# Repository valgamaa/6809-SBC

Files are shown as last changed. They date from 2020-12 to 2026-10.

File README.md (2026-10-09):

# 6809 SBC

A self-built 6809 single-board computer that runs **FLEX 9** from a
CompactFlash card: schematics and boards, the firmware and drivers that run
on it, and the host-side tools used with it.

## Contents

| Folder | Contents |
|---|---|
| [`hardware/`](hardware/) | Schematics and board files (current version: V6) |
| [`software/`](software/) | Monitor, FLEX BIOS and disk drivers, RTC support, CF tools and the ROM image — see [software/README.md](software/README.md) |
| [`tools/octave/`](tools/octave/) | Octave scripts for FLEX disk images and S-record handling |

The companion Mac application [A09Studio](https://github.com/valgamaa/A09Studio)
assembles the code, programs the ROM, sends FLEX disk images to the CF card,
and browses and builds FLEX disks.

## Licence

The code in this repository is released under the [MIT licence](LICENSE).
Parts derive from third-party software; see [NOTICE.md](NOTICE.md). FLEX and
TSC programs are not included and belong to their owners.

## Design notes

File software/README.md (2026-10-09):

# 6809 SBC software

Firmware, drivers and test programs for a self-built 6809 single-board
computer that runs **FLEX 9** from a CompactFlash card.

The board: 6809 CPU, 1 MHz bus from a 4 MHz crystal, MC68681 DUART for the
console, CompactFlash in 16-bit True IDE mode (low byte only), Epson
RTC-72421/72423 real-time clock, and an MC6859 data-security device. The
monitor is a modified **Assist09**; at reset it copies itself from ROM to RAM.

The host-side tools for building these programs and for making and sending
FLEX disk images are in the companion project,
[A09Studio](https://github.com/valgamaa/A09Studio).

## What is here

| Folder | Contents |
|---|---|
| `monitor/` | `Assist09-Flex.asm` — the modified Assist09 monitor: boots FLEX, reads the RTC and sets FLEX's date, and adds the `F`, `X`, `U` and `K` commands |
| `rtc/` | RTC support: `Assist09_Flex_RTC.asm` (date sync and 1-minute interrupt, called from the monitor), `Flex_DatePatch.asm` (stops FLEX asking for the date), `RTC_Set.asm` (the clock-setting program run by `K`), and RTC test programs |
| `flex-bios/` | `Flex_BIOS.asm` — FLEX's disk and console drivers for the CF card and serial port; `Flex_BIOS_DiskLoader.asm` — receives a FLEX disk image over serial and writes it to the card; `inch_outch_test.asm` — console I/O test |
| `cf-tools/` | `FlexFormat.asm` — formats a FLEX disk on the CF card; `CF_Test_4.asm` — CF card exerciser |
| `rom-images/` | The programmed ROM image (v6) as `.bin` and `.hex` |
| `docs/` | `monitor-commands.md` / [PDF](docs/monitor-commands.pdf) (the added commands), `xbasic-patching.md`, and a spreadsheet of the added commands |

Each source file has a header comment saying what it does and where it lives
in memory. The `.hex` / `.s19` files are assembler output kept for convenience.

## Hardware addresses

| Address | Device |
|---|---|
| `$F000`–`$F7FF` | I/O space (decoded as a 2K block) |
| `$F230` | Epson RTC |
| `$F278` | MC6859 (responds in the top 8 bytes of its decode window) |
| `$F2C0`, `$F300` | CompactFlash register blocks |
| `$F340` | MC68681 DUART, port A (console) |

Software entry points and load addresses (for example `Flex_BIOS` at `$F800`
with its disk vector table at `$DE00`, the RTC sync routine at `$FB00`, and the
disk loader at `$EE00`) are given in each source file's header comment.

## Building

The sources assemble with the `a09` assembler. For example:

```
a09 -xFlex_BIOS.hex -lFlex_BIOS.lst Flex_BIOS.asm
```

`-x` writes Intel hex, `-s` S-records, `-b` raw binary and `-l` a listing.
A09Studio wraps the same assembler with an editor and a terminal, and drives
a TL866 programmer to burn the ROM.

> TODO: add step-by-step instructions for assembling the pieces into the
> combined ROM image and burning it.

## Bring-up order

1. Burn the ROM image (`rom-images/`) and check the monitor prompt on the serial console.
2. Format the CF card with the monitor's `X` command, or send a whole disk image to it with `U` and the Disk Image tool in A09Studio.
3. Use `K` to set the clock, then boot FLEX with `F`. The monitor sets FLEX's date from the RTC.

The monitor's added commands (`F`, `X`, `U`, `K`) are described in
[docs/monitor-commands.md](docs/monitor-commands.md).

## Using TSC Extended BASIC

TSC XBASIC needs a few per-system patches before it runs on this board. See
[docs/xbasic-patching.md](docs/xbasic-patching.md). The program itself is not
included here.

## Licence

The code in this repository is released under the [MIT licence](../LICENSE).
Parts of it derive from third-party software; see [NOTICE.md](../NOTICE.md).
FLEX and TSC programs are not included and belong to their owners.

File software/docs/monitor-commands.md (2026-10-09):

# Added monitor commands

The monitor is Assist09 with four commands added. All of them use letters
that stock Assist09 does not use (it already uses B, C, D, E, G, L, M, N, O,
P, R, S, T, V and W). The ROM image is
`rom-images/Monolithic-Flex-Assist09-BIOS-Format-Loader_v6`.

| Command | Name | Runs at | Source |
|---|---|---|---|
| `F` | Boot FLEX | `$CD00` | `monitor/Assist09-Flex.asm`, `rtc/Assist09_Flex_RTC.asm`, `rtc/Flex_DatePatch.asm` |
| `X` | Format | `$E900` | `cf-tools/FlexFormat.asm` |
| `U` | Upload | `$EE00` | `flex-bios/Flex_BIOS_DiskLoader.asm` |
| `K` | Clock | `$C000` | `rtc/RTC_Set.asm` |

## `F` — boot FLEX

Starts FLEX, with the date taken from the real-time clock.

1. Reads the RTC and prints it as `DD/MM/YY HH:MM:SS`. If the clock is unset
   or holds an impossible date, it prints a message instead.
2. Writes the date into FLEX's date bytes (`$CC0E`–`$CC10`).
3. Arms the RTC's 1-minute interrupt, so the date stays current without
   anyone typing `DATE`.
4. Waits for the console to finish printing, then starts FLEX.

FLEX skips its "date?" prompt when the date has been set. If the clock can't
be read, FLEX starts with whatever date it already had and the interrupt
stays off. Use `K` to set the clock.

## `X` — format

Starts the disk formatter, which formats the CF card for FLEX. It writes a
new, empty FLEX disk: the System Information Record, an empty directory, and
a free-space chain over the rest of the card. **This erases the disk.**

## `U` — upload

Starts the disk loader. Once it is running, send a disk image from the host
over the serial link and it is written to the CF card, sector by sector. In
A09Studio use the **Disk Image…** tool (or **Send to CF…** from the Disk
Builder or DSK Browser). This overwrites the target drive.

## `K` — clock

Starts the clock program, for setting the time and date from scratch or for
checking a new board. **Starting it stops and resets the clock.** At its
prompt:

| Key | Action |
|---|---|
| `S` | Set the time |
| `E` | Set the date (`DD MM YY`) |
| `I` | Toggle the 1-minute interrupt |
| `Q` | Quit back to the monitor |

After setting the clock, use `F` to boot FLEX with the new date.

## Notes

- The formatter, loader and clock program sit in ROM above or away from user
  RAM, so `$0000`–`$BFFF` stays free. The clock program at `$C000` is
  restored from the ROM image on every reset.
- The monitor masks the RTC interrupt at reset, so a cold power-up can't fire
  it before `F` has installed the handler.

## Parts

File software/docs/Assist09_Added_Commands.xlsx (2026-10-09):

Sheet: Added commands
Command | Name | Address | What it does | Source file
F | Boot Flex | $CD00 | Reads the RTC and prints DD/MM/YY HH:MM:SS (or a message if the clock is unset or invalid). Writes the date to Flex's date bytes at $CC0E-$CC10, arms the 1-minute RTC interrupt, waits for the console to finish printing, then starts Flex. Flex skips its date prompt when the date was set. | Assist09-Flex.asm, Assist09_Flex_RTC.asm, Flex_DatePatch.asm
X | Format | $E900 | Launches the disk formatter to format the CF card for Flex. | FlexFormat.asm
U | Upload | $EE00 | Launches the disk loader. Once running, send a disk image from the host over serial and it writes it to the CF card. | Flex_BIOS_DiskLoader.asm
K | Clock | $C000 | Launches the clock program for setting the time and date from scratch or checking a new board. S sets the time, E sets the date (DD MM YY), I toggles the minute interrupt, Q returns to the monitor. Starting it stops and resets the clock. | RTC_Set.asm

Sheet: Notes
The formatter, loader and clock program sit in ROM above or away from user RAM, so $0000-$BFFF stays free. The clock program at $C000 is restored from the ROM image on every reset.
The monitor masks the RTC interrupt at reset so a cold power-up cannot fire it before F has installed the handler.
Letters already used by stock Assist09: B, C, D, E (encode), G, L, M, N, O, P, R, S, T, V, W.
Image: Monolithic-Flex-Assist09-BIOS-Format-Loader_v6.

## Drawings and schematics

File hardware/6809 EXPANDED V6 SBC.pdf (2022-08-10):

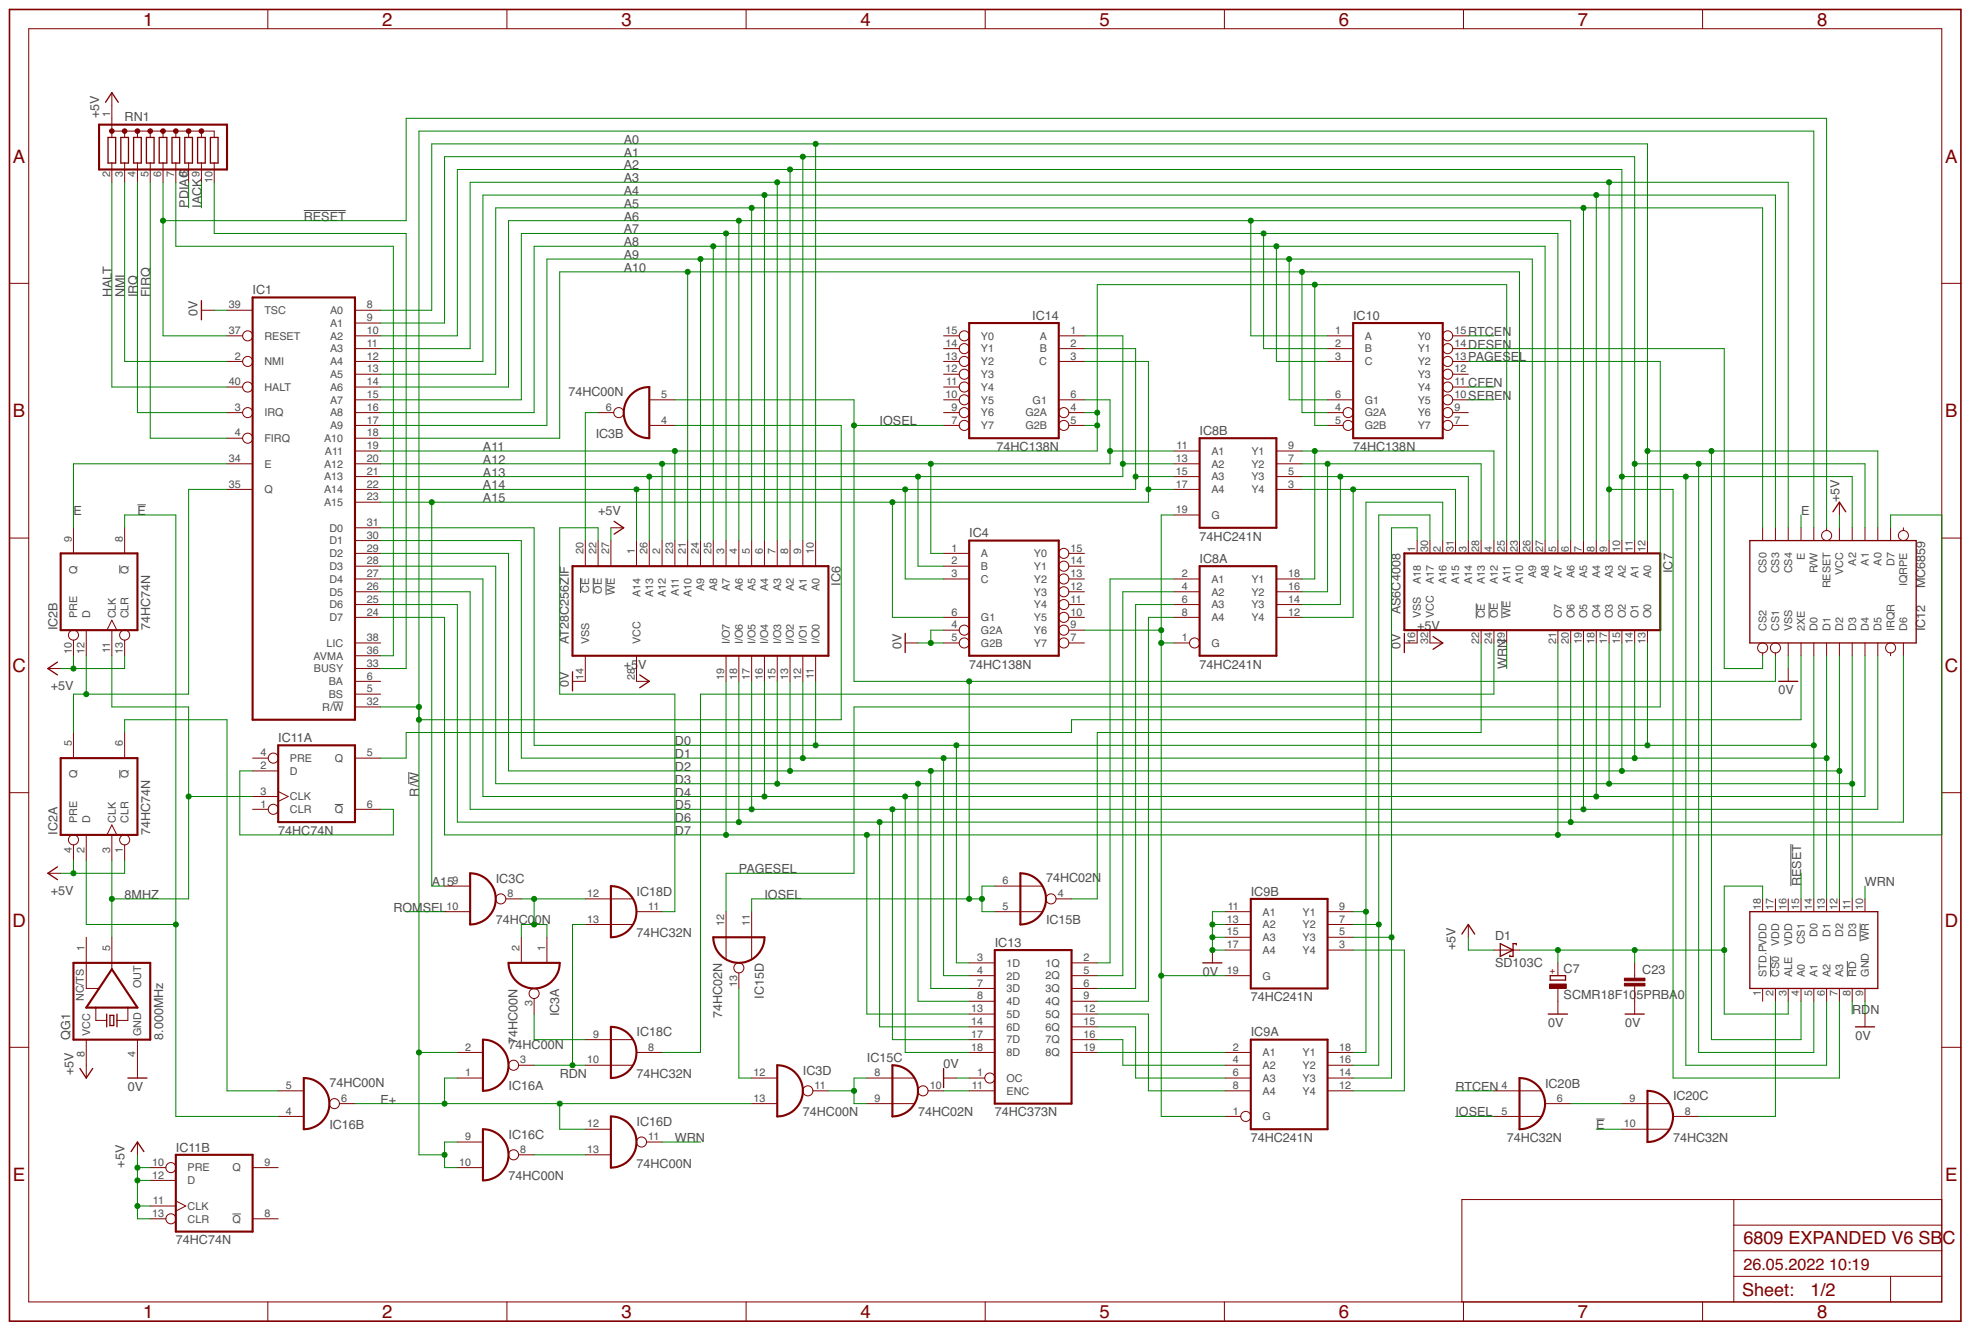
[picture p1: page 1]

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
22 | | A14 | | | | | 3 Y3
23 | | A15 | | | | 19

13 | 7 Y1
15 | 5 Y2

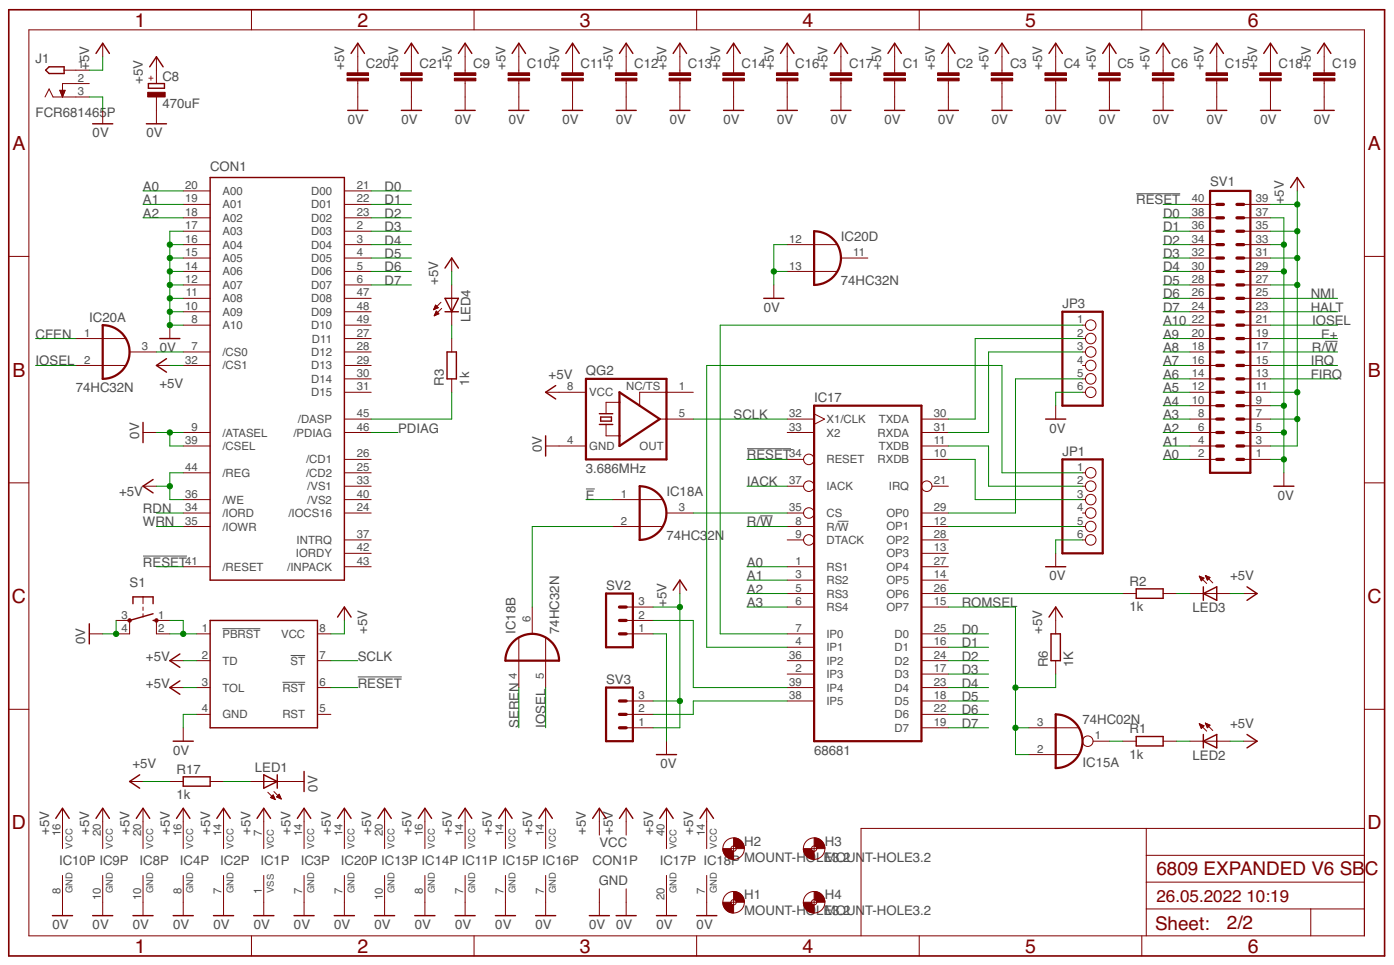
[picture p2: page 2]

CON1

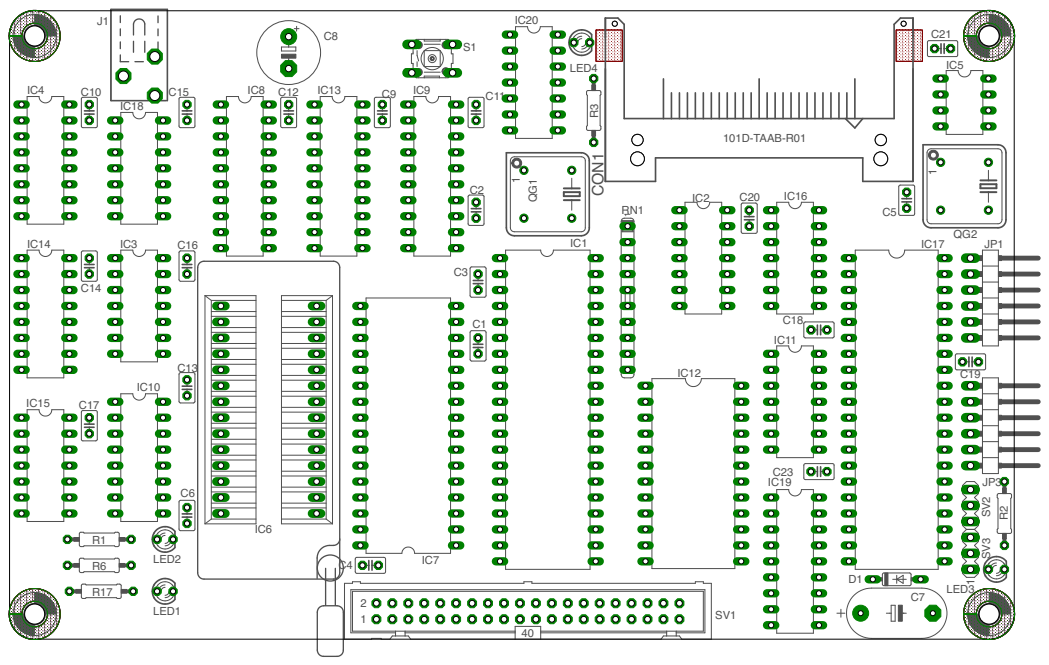
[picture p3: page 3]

Qty Device | PCB Ref. | TME Order Code
1 | B3F-10XX | S1 | SKHHALA010
1 | MI20-50PD-SF | CON1 | 101D-TAAB-R01
2 | MA03-1 | SV2, SV3 | 77311-818-03LF
1 | ML40 | SV1 | ZL231-40PG
2 | 1X06/90 | JP1, JP3 | ZL263-6SG
1 | FCR681465P | J1 | FCR681465P
5 | 1k | R1, R2, R3, R6, R17 | MBB0207C1001FCT00
1 | 4k7 | RN1 | 4610X-101-472LF
20 100n | C1, C2, C3, C4, C5, C6, C9, C10,
| | C11, C12, C13, C14, C15, C16, C17,
| | C18, C19, C20, C21, C23
1 | 470uF | C8 | UVY1E471MPD
1 | SCMR18F105PRBA0 | C7
1 | 3.686MHz | QG2
1 | 8.000MHz | QG1
2 | 74HC00N | IC3, IC16
1 | 74HC02N | IC15
3 | 74HC138N | IC4, IC10, IC14
2 | 74HC241N | IC8, IC9
2 | 74HC32N | IC18, IC20
1 | 74HC373N | IC13
2 | 74HC74N | IC2, IC11
1 | 6809E | IC1
1 | MC68681P | IC17
1 | AS6C4008 | IC7
1 | AT28C256ZIF | IC6
1 | TC1232 | IC5
1 | MC6859 | IC12
1 | RTC72421 | IC19
1 | SD103C | D1
4 | LED3MM | LED1, LED2, LED3, LED4

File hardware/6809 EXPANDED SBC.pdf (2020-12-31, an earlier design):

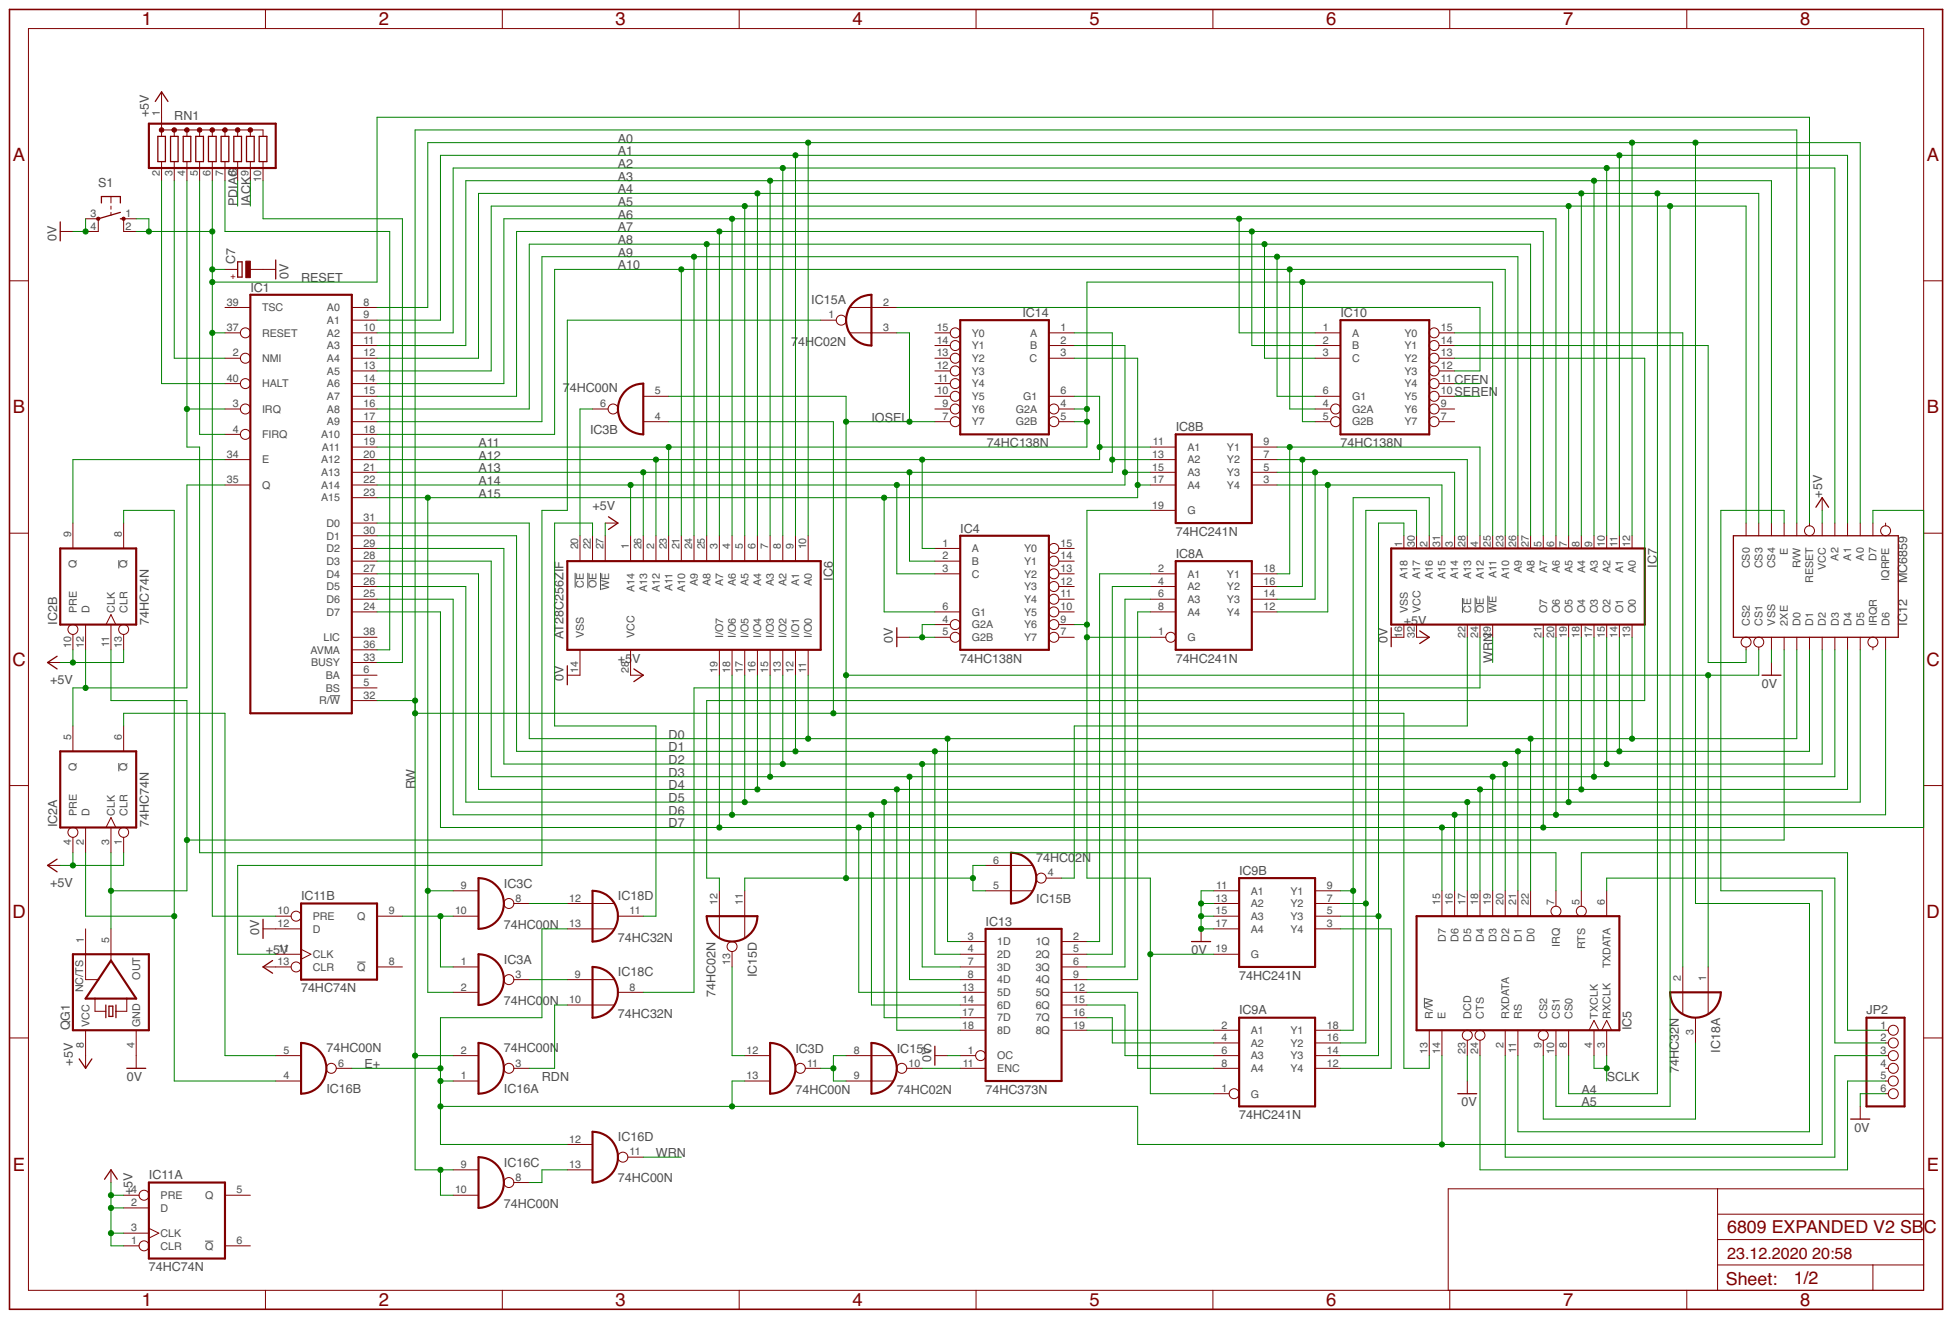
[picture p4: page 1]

A3
A4
A5

23 | A15
31 | | +5V

D0 D1 D7
D2 D3 D4 D5 D6

14 | | 15
17 | | 16

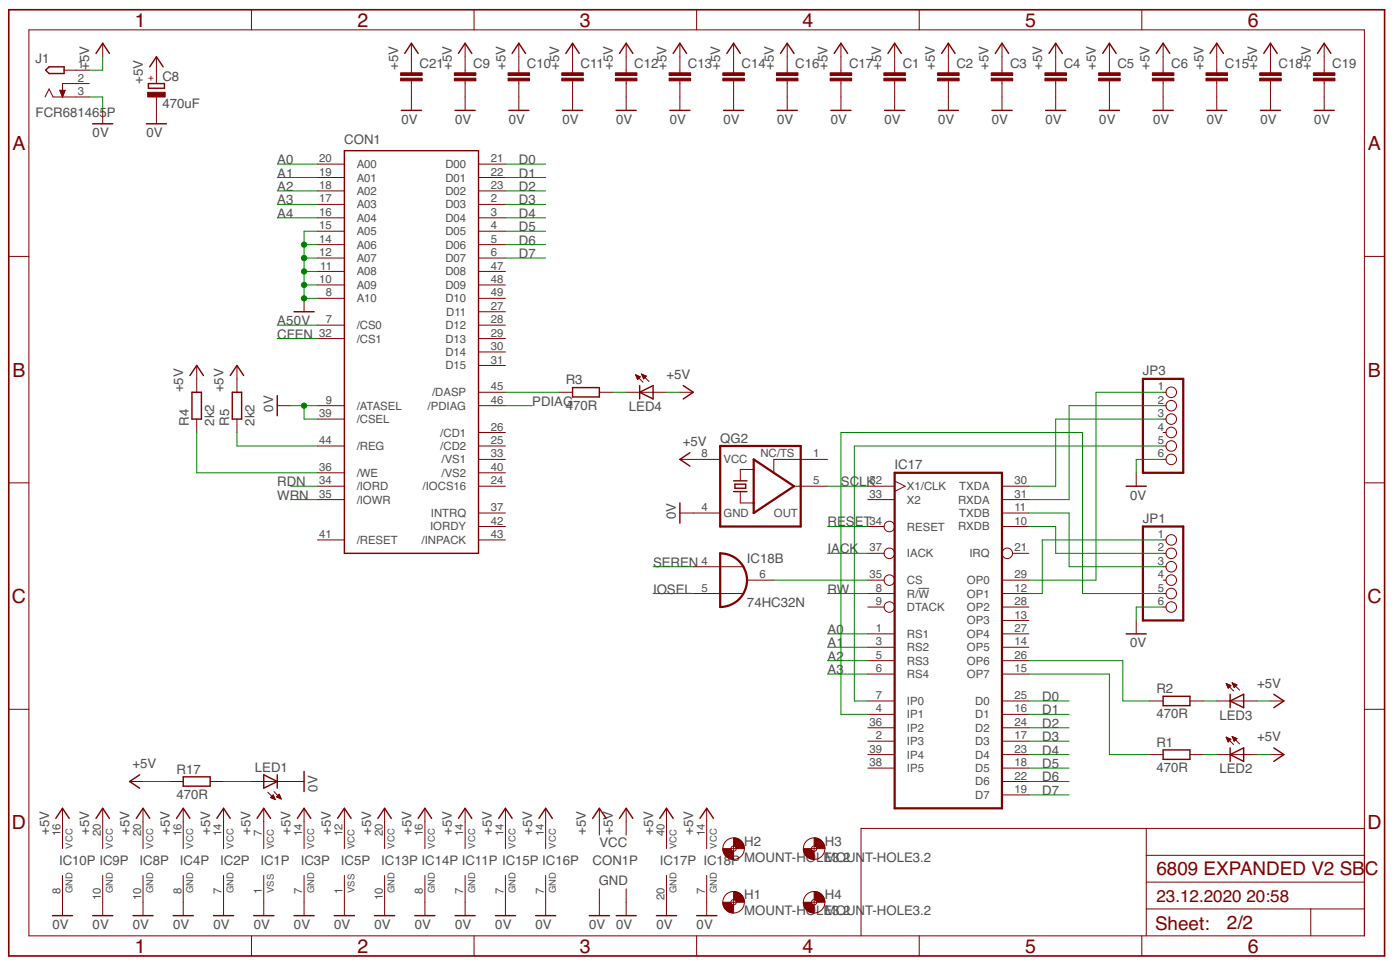
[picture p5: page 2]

CON1

14 | 5 D6
12 | 6 D7

10 | 48
8 | 49
7 | 27

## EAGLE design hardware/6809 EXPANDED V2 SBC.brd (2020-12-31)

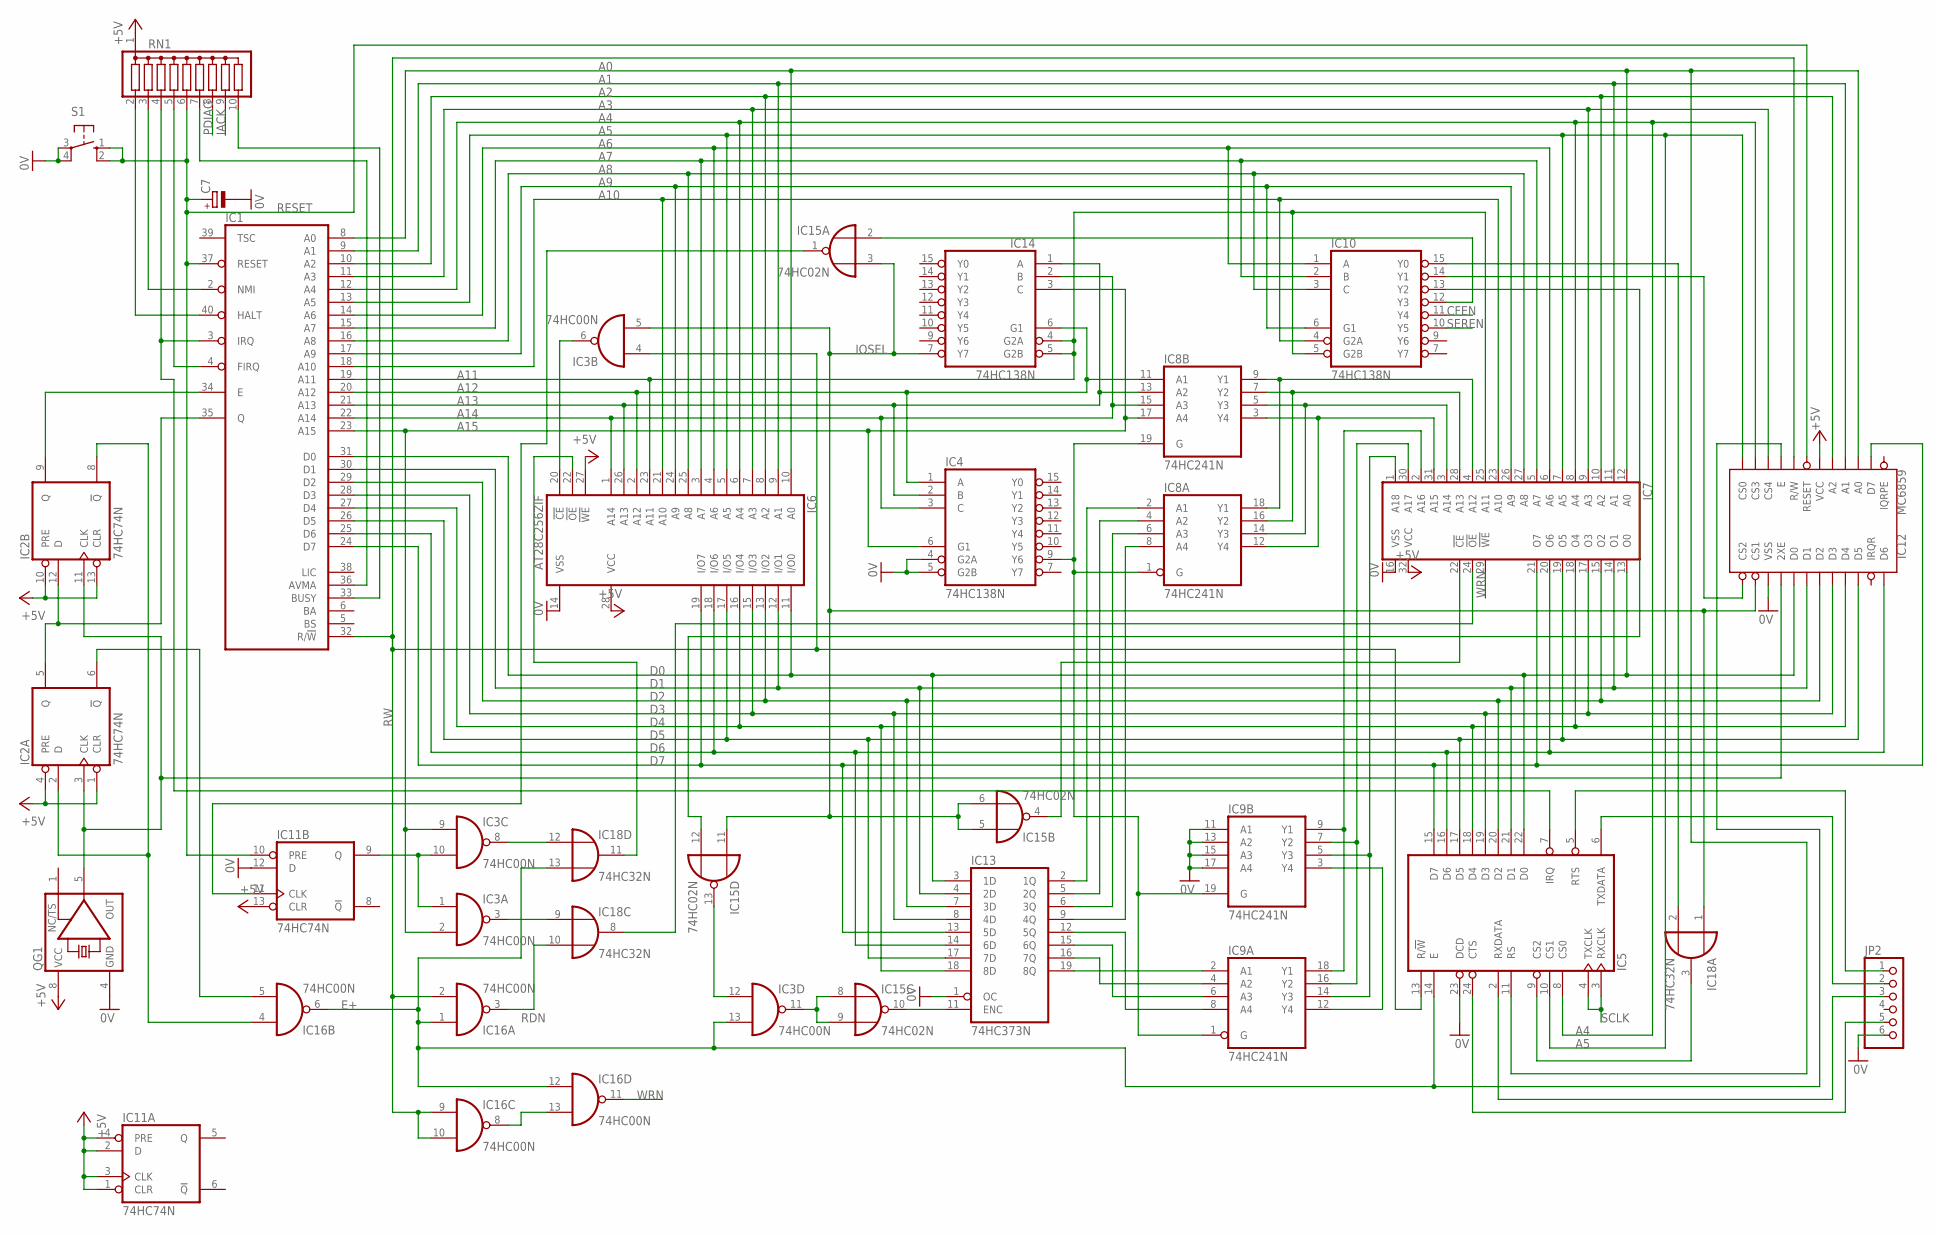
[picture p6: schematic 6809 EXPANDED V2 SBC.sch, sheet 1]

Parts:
C7: CPOL-EUE2-5; E2-5
IC1: 6809E; DIL40
IC2, IC11: 74HC74N; DIL14
IC3, IC16: 74HC00N; DIL14
IC4, IC10, IC14: 74HC138N; DIL16
IC5: 6850; DIL24
IC6: AT28C256ZIF; 228-1277-00-0602J
IC7: AS6C4008; DIL32
IC8, IC9: 74HC241N; DIL20
IC12: MC6859; DIL24-6
IC13: 74HC373N; DIL20
IC15: 74HC02N; DIL14
IC18: 74HC32N; DIL14
JP2: PINHD-1X6/90; 1X06/90
QG1: XO-8; DIL08S
RN1: G09R; SIL10
S1: 10-XX; B3F-10XX

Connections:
0V: C7.-, IC4.4 (G2A), IC4.5 (G2B), IC5.23 (DCD), IC6.14 (VSS), IC7.16 (VSS), IC9.11 (A1), IC9.13 (A2), IC9.15 (A3), IC9.17 (A4), IC11.12 (D), IC12.15 (VSS), IC13.1 (OC), JP2.6, QG1.4 (GND), S1.3, S1.4 (P1); also elsewhere on the board
+5V: IC2.1 (CLR), IC2.4 (PRE), IC2.10 (PRE), IC2.13 (CLR), IC6.27 (!WE), IC6.28 (VCC), IC7.32 (VCC), IC11.1 (CLR), IC11.2 (D), IC11.3 (CLK), IC11.4 (PRE), IC11.13 (CLR), IC12.6 (VCC), QG1.8 (VCC), RN1.1; also elsewhere on the board
A0: IC1.8 (A0), IC5.11 (RS), IC6.10 (A0), IC7.12 (A0), IC12.3 (A0); also elsewhere on the board
A1: IC1.9 (A1), IC6.9 (A1), IC7.11 (A1), IC12.4 (A1); also elsewhere on the board
A2: IC1.10 (A2), IC6.8 (A2), IC7.10 (A2), IC12.5 (A2); also elsewhere on the board
A3: IC1.11 (A3), IC6.7 (A3), IC7.9 (A3), IC12.10 (CS4); also elsewhere on the board
A4: IC1.12 (A4), IC5.8 (CS0), IC6.6 (A4), IC7.8 (A4), IC12.11 (CS3); also elsewhere on the board
A5: IC1.13 (A5), IC5.10 (CS1), IC6.5 (A5), IC7.7 (A5), IC12.12 (CS0); also elsewhere on the board
A6: IC1.14 (A6), IC6.4 (A6), IC7.6 (A6), IC10.1 (A)
A7: IC1.15 (A7), IC6.3 (A7), IC7.5 (A7), IC10.2 (B)
A8: IC1.16 (A8), IC6.25 (A8), IC7.27 (A8), IC10.3 (C)
A9: IC1.17 (A9), IC6.24 (A9), IC7.26 (A9), IC10.6 (G1)
A10: IC1.18 (A10), IC6.21 (A10), IC7.23 (A10), IC10.4 (G2A)
A11: IC1.19 (A11), IC6.23 (A11), IC7.25 (A11), IC10.5 (G2B), IC14.4 (G2A), IC14.5 (G2B)
A12: IC1.20 (A12), IC4.1 (A), IC6.2 (A12), IC8.11 (A1), IC14.6 (G1)
A13: IC1.21 (A13), IC4.2 (B), IC6.26 (A13), IC8.13 (A2), IC14.1 (A)
A14: IC1.22 (A14), IC4.3 (C), IC6.1 (A14), IC8.15 (A3), IC14.2 (B)
A15: IC1.23 (A15), IC3.2 (I1), IC3.9 (I0), IC4.6 (G1), IC8.17 (A4), IC14.3 (C)
CFEN: IC10.11 (Y4); also elsewhere on the board
D0: IC1.31 (D0), IC5.22 (D0), IC6.11 (I/O0), IC7.13 (O0), IC12.17 (D0), IC13.3 (1D); also elsewhere on the board
D1: IC1.30 (D1), IC5.21 (D1), IC6.12 (I/O1), IC7.14 (O1), IC12.18 (D1), IC13.4 (2D); also elsewhere on the board
D2: IC1.29 (D2), IC5.20 (D2), IC6.13 (I/O2), IC7.15 (O2), IC12.19 (D2), IC13.7 (3D); also elsewhere on the board
D3: IC1.28 (D3), IC5.19 (D3), IC6.15 (I/O3), IC7.17 (O3), IC12.20 (D3), IC13.8 (4D); also elsewhere on the board
D4: IC1.27 (D4), IC5.18 (D4), IC6.16 (I/O4), IC7.18 (O4), IC12.21 (D4), IC13.18 (8D); also elsewhere on the board
D5: IC1.26 (D5), IC5.17 (D5), IC6.17 (I/O5), IC7.19 (O5), IC12.22 (D5), IC13.17 (7D); also elsewhere on the board
D6: IC1.25 (D6), IC5.16 (D6), IC6.18 (I/O6), IC7.20 (O6), IC12.24 (D6), IC13.14 (6D); also elsewhere on the board
D7: IC1.24 (D7), IC5.15 (D7), IC6.19 (I/O7), IC7.21 (O7), IC12.2 (D7), IC13.13 (5D); also elsewhere on the board
E+: IC3.13 (I1), IC5.14 (E), IC12.9 (E), IC16.1 (I0), IC16.6 (O), IC16.12 (I0), IC18.13 (I1)
IACK: RN1.9; also elsewhere on the board
IOSEL: IC3.5 (I1), IC12.14 (CS1), IC14.7 (Y7), IC15.3 (I1), IC15.5 (I0), IC15.6 (I1), IC15.11 (I0), IC18.1 (I0); also elsewhere on the board
unnamed: IC2.6 (!Q), IC16.5 (I1)
unnamed: IC2.2 (D), IC2.8 (!Q), IC16.4 (I0)
unnamed: IC2.3 (CLK), IC2.11 (CLK), IC12.16 (2XE), QG1.5 (OUT)
unnamed: IC1.4 (FIRQ), RN1.5
unnamed: IC1.35 (Q), IC2.5 (Q), IC2.12 (D)
unnamed: IC3.12 (I0), IC15.13 (O)
unnamed: IC10.13 (Y2), IC15.12 (I1)
unnamed: IC3.11 (O), IC15.8 (I0), IC15.9 (I1)
unnamed: IC1.34 (E), IC2.9 (Q)
unnamed: IC3.1 (I0), IC3.10 (I1), IC11.9 (Q)
unnamed: IC7.22 (!CE), IC15.4 (O)
unnamed: IC10.12 (Y3), IC15.2 (I0)
unnamed: IC3.3 (O), IC18.9 (I0)
unnamed: IC11.11 (CLK), IC15.1 (O)
unnamed: IC7.24 (!OE), IC18.8 (O)
unnamed: IC6.22 (!OE), IC18.11 (O)
unnamed: IC9.2 (A1), IC13.19 (8Q)
unnamed: IC13.11 (ENC), IC15.10 (O)
unnamed: IC16.8 (O), IC16.13 (I1)
unnamed: IC3.8 (O), IC18.12 (I0)
unnamed: IC10.14 (Y1), IC12.13 (CS2)
unnamed: IC5.5 (RTS), JP2.1
unnamed: IC1.40 (HALT), RN1.2
unnamed: IC3.6 (O), IC6.20 (!CE)
unnamed: IC1.36 (AVMA), RN1.7
unnamed: IC1.33 (BUSY), RN1.10
unnamed: IC1.3 (IRQ), IC5.7 (IRQ), RN1.4
unnamed: IC5.24 (CTS), JP2.5
unnamed: IC1.2 (NMI), RN1.3
unnamed: IC5.6 (TXDATA), JP2.2
unnamed: IC5.2 (RXDATA), JP2.3
unnamed: IC4.9 (Y6), IC8.1 (G), IC8.19 (G), IC9.1 (G), IC9.19 (G)
unnamed: IC7.4 (A12), IC8.9 (Y1), IC8.18 (Y1)
unnamed: IC7.28 (A13), IC8.7 (Y2), IC8.16 (Y2)
unnamed: IC7.3 (A14), IC8.5 (Y3), IC8.14 (Y3)
unnamed: IC7.31 (A15), IC8.3 (Y4), IC8.12 (Y4)
unnamed: IC9.8 (A4), IC13.12 (5Q)
unnamed: IC10.15 (Y0), IC18.2 (I1)
unnamed: IC9.4 (A2), IC13.16 (7Q)
unnamed: IC9.6 (A3), IC13.15 (6Q)
unnamed: IC7.2 (A16), IC9.9 (Y1), IC9.18 (Y1)
unnamed: IC7.30 (A17), IC9.7 (Y2), IC9.16 (Y2)
unnamed: IC7.1 (A18), IC9.5 (Y3), IC9.14 (Y3)
unnamed: IC9.3 (Y4), IC9.12 (Y4)
unnamed: IC8.8 (A4), IC13.9 (4Q)
unnamed: IC8.6 (A3), IC13.6 (3Q)
unnamed: IC8.4 (A2), IC13.5 (2Q)
unnamed: IC8.2 (A1), IC13.2 (1Q)
unnamed: IC5.9 (CS2), IC18.3 (O)
PDIAG: RN1.8; also elsewhere on the board
RDN: IC16.3 (O), IC18.10 (I1); also elsewhere on the board
RESET: C7.+, IC1.37 (RESET), IC11.10 (PRE), IC12.7 (RESET), RN1.6, S1.1 (S), S1.2 (S1); also elsewhere on the board
RW: IC1.32 (R/!W), IC3.4 (I0), IC5.13 (R/!W), IC12.8 (R/W), IC16.2 (I1), IC16.9 (I0), IC16.10 (I1); also elsewhere on the board
SCLK: IC5.3 (RXCLK), IC5.4 (TXCLK); also elsewhere on the board
SEREN: IC10.10 (Y5); also elsewhere on the board
WRN: IC7.29 (!WE), IC16.11 (O); also elsewhere on the board

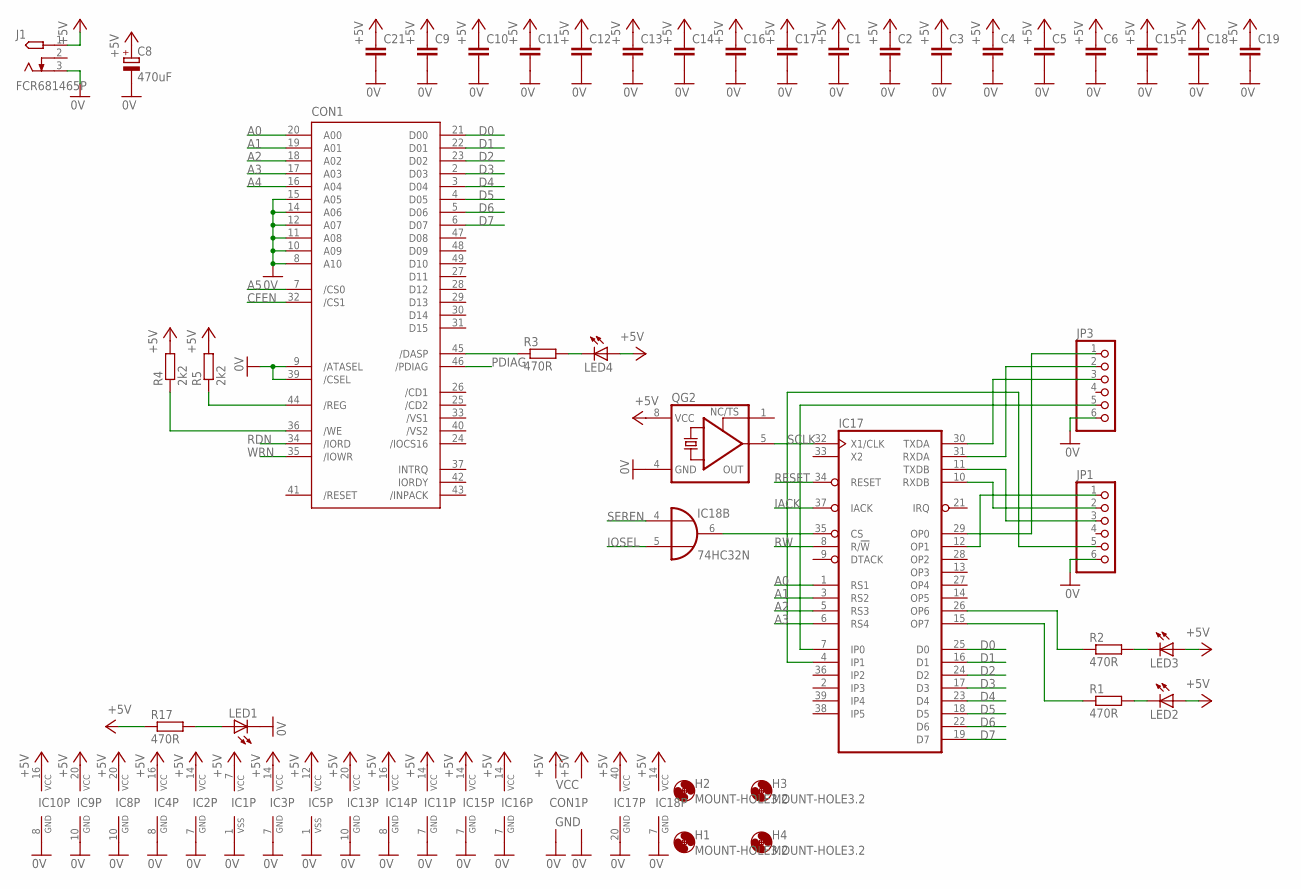
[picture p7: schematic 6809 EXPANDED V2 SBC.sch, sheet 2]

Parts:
C1, C2, C3, C4, C5, C6, C9, C10, C11, C12, C13, C14, C15, C16, C17, C18, C19, C21: C-EU025-025X050; C025-025X050
C8: 470uF; E5-10,5
CON1: CF-CARD-IDE_MODE; MI20-50PD-SF
H1, H2, H3, H4: MOUNT-HOLE3.2; 3,2
IC1: 6809E; DIL40
IC2, IC11: 74HC74N; DIL14
IC3, IC16: 74HC00N; DIL14
IC4, IC10, IC14: 74HC138N; DIL16
IC5: 6850; DIL24
IC8, IC9: 74HC241N; DIL20
IC13: 74HC373N; DIL20
IC15: 74HC02N; DIL14
IC17: MC68681P; DIL40
IC18: 74HC32N; DIL14
J1: FCR681465P
JP1, JP3: PINHD-1X6/90; 1X06/90
LED1, LED2, LED3, LED4: LED3MM
QG2: XO-8; DIL08S
R1, R2, R3, R17: 470R; 0207/10
R4, R5: 2k2; 0207/10

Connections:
0V: C1.2, C2.2, C3.2, C4.2, C5.2, C6.2, C8.-, C9.2, C10.2, C11.2, C12.2, C13.2, C14.2, C15.2, C16.2, C17.2, C18.2, C19.2, C21.2, CON1.1 (GND1), CON1.8 (A10), CON1.9 (/ATASEL), CON1.10 (A09), CON1.11 (A08), CON1.12 (A07), CON1.14 (A06), CON1.15 (A05), CON1.39 (/CSEL), CON1.50 (GND2), IC1.1 (VSS), IC2.7 (GND), IC3.7 (GND), IC4.8 (GND), IC5.1 (VSS), IC8.10 (GND), IC9.10 (GND), IC10.8 (GND), IC11.7 (GND), IC13.10 (GND), IC14.8 (GND), IC15.7 (GND), IC16.7 (GND), IC17.20 (GND), IC18.7 (GND), J1.3, JP1.6, JP3.6, LED1.K (C), QG2.4 (GND); also elsewhere on the board
+5V: C1.1, C2.1, C3.1, C4.1, C5.1, C6.1, C8.+, C9.1, C10.1, C11.1, C12.1, C13.1, C14.1, C15.1, C16.1, C17.1, C18.1, C19.1, C21.1, CON1.13 (VCC2), CON1.38 (VCC1), IC1.7 (VCC), IC2.14 (VCC), IC3.14 (VCC), IC4.16 (VCC), IC5.12 (VCC), IC8.20 (VCC), IC9.20 (VCC), IC10.16 (VCC), IC11.14 (VCC), IC13.20 (VCC), IC14.16 (VCC), IC15.14 (VCC), IC16.14 (VCC), IC17.40 (VCC), IC18.14 (VCC), J1.1, LED2.A, LED3.A, LED4.A, QG2.8 (VCC), R4.2, R5.2, R17.1; also elsewhere on the board
A0: CON1.20 (A00), IC17.1 (RS1); also elsewhere on the board
A1: CON1.19 (A01), IC17.3 (RS2); also elsewhere on the board
A2: CON1.18 (A02), IC17.5 (RS3); also elsewhere on the board
A3: CON1.17 (A03), IC17.6 (RS4); also elsewhere on the board
A4: CON1.16 (A04); also elsewhere on the board
A5: CON1.7 (/CS0); also elsewhere on the board
CFEN: CON1.32 (/CS1); also elsewhere on the board
D0: CON1.21 (D00), IC17.25 (D0); also elsewhere on the board
D1: CON1.22 (D01), IC17.16 (D1); also elsewhere on the board
D2: CON1.23 (D02), IC17.24 (D2); also elsewhere on the board
D3: CON1.2 (D03), IC17.17 (D3); also elsewhere on the board
D4: CON1.3 (D04), IC17.23 (D4); also elsewhere on the board
D5: CON1.4 (D05), IC17.18 (D5); also elsewhere on the board
D6: CON1.5 (D06), IC17.22 (D6); also elsewhere on the board
D7: CON1.6 (D07), IC17.19 (D7); also elsewhere on the board
IACK: IC17.37 (IACK); also elsewhere on the board
IOSEL: IC18.5 (I1); also elsewhere on the board
unnamed: IC17.35 (CS), IC18.6 (O)
unnamed: LED1.A, R17.2
unnamed: IC17.31 (RXDA), JP3.2
unnamed: IC17.30 (TXDA), JP3.3
unnamed: IC17.11 (TXDB), JP1.3
unnamed: IC17.10 (RXDB), JP1.2
unnamed: IC17.7 (IP0), JP3.5
unnamed: IC17.4 (IP1), JP1.5
unnamed: IC17.29 (OP0), JP3.1
unnamed: LED3.K (C), R2.2
unnamed: IC17.12 (OP1), JP1.1
unnamed: LED2.K (C), R1.2
unnamed: IC17.26 (OP6), R2.1
unnamed: IC17.15 (OP7), R1.1
unnamed: CON1.45 (/DASP), R3.1
unnamed: LED4.K (C), R3.2
unnamed: CON1.44 (/REG), R5.1
unnamed: CON1.36 (/WE), R4.1
PDIAG: CON1.46 (/PDIAG); also elsewhere on the board
RDN: CON1.34 (/IORD); also elsewhere on the board
RESET: IC17.34 (RESET); also elsewhere on the board
RW: IC17.8 (R/!W); also elsewhere on the board
SCLK: IC17.32 (X1/CLK), QG2.5 (OUT); also elsewhere on the board
SEREN: IC18.4 (I0); also elsewhere on the board
WRN: CON1.35 (/IOWR); also elsewhere on the board

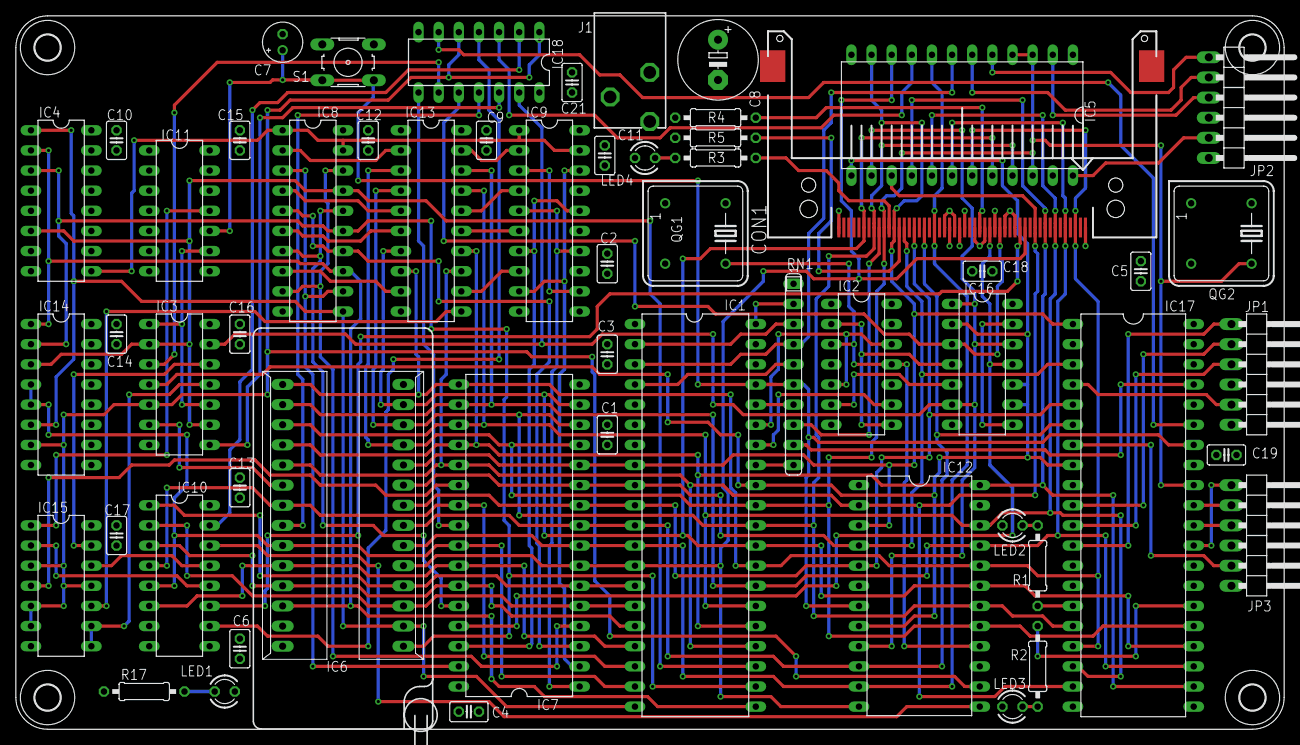
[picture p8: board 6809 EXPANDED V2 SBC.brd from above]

Board: 4 copper layers, 160.0 x 90.0 mm, 61 parts (0 on the bottom side), 104 nets.

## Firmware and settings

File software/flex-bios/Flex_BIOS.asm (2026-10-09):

********************************************
* MC68681 REGISTER EQUATES
********************************************
PORTA		EQU		$F340
PORTB		EQU		$F348
* Read registers
ModeReg		EQU     0           	; Mode Register 
Status		EQU     1         		; Status Register 
RxBuff		EQU     3         		; Receiver Buffer 
PortCR		EQU     4         		; Input Port Change Register
IntReg		EQU     5         		; Interrupt Staus Register
CounterMSBA	EQU     6         		; Counter Mode: MSB
CounterLSBA	EQU     7         		; Counter Mode: LSB
StartCount1	EQU     14        		; Start-counter command
StartCount2	EQU     15        		; Start-counter command

* Write registers
ClkSel		EQU     1          		; Clock-Select Register 
Command		EQU     2          		; Command register 
TxBuff		EQU     3          		; Transmitter buffer 
AuxCont		EQU     4          		; Auxillary control register
IntMask		EQU     5          		; Interrupt mask register
CTUpper		EQU     6          		; Counter/timer upper register
CTLower		EQU     7          		; Counter/timer lower register
OPSet		EQU     14         		; Output port set bits
OPReset		EQU     15         		; Output port reset bits
*******************************************
* CF REGS
*******************************************
CFADDRESS1	EQU 	$F2C0
CFADDRESS2	EQU 	$F300
CFDATA		EQU		$00		; DATA PORT
CFERROR		EQU		$01		; ERROR CODE (READ)
CFFEATURE	EQU		$01		; FEATURE SET (WRITE)
CFSECCNT	EQU		$02		; NUMBER OF SECTORS TO TRANSFER
CFLBA0		EQU		$03		; SECTOR ADDRESS LBA 0 [0:7]
CFLBA1		EQU		$04		; SECTOR ADDRESS LBA 1 [8:15]
CFLBA2		EQU		$05		; SECTOR ADDRESS LBA 2 [16:23]
CFLBA3		EQU		$06		; SECTOR ADDRESS LBA 3 [24:27 (LSB)]
CFSTATUS	EQU		$07		; STATUS (READ)
CFCOMMAND	EQU		$07		; COMMAND SET (WRITE)

CFSTATUSL1	EQU		CFADDRESS1+CFSTATUS
CFSTATUSL2	EQU		CFADDRESS2+CFSTATUS
CFTIMEOUT	EQU		$FFFF		; Busy/ready poll timeout for DATWAIT/CMDWAIT/
CMDTIMEOUT	EQU		$0800		; Poll timeout for CMDWAIT only (about 47ms at a 1MHz
							; E clock). A present card answers at once; this just
							; stops an EMPTY slot costing ~1.5s per CMDWAIT, which
							; made Flex boot very slow with a single CF card fitted.
CFBYTETO	EQU		$0200		; Much smaller timeout for DRQWAITB, the
							; per-byte DRQ recheck inside READ's transfer
							; loop -- that's meant to catch a brief, one-
							; off drop (a shallow FIFO refill), not wait as
							; long as a fresh command issue. Using the full
							; CFTIMEOUT there let a single stuck sector burn
							; through up to 256 full-length timeouts (one per
							; byte), which is what actually hung -- not a true
							; infinite loop, just a very long one. Raise this
							; if a real, present card ever times out here.
							; DRQWAIT -- counts down once per poll rather
							; than looping forever, so a card that never
							; responds (e.g. an empty CF slot) doesn't hang
							; the driver. Not calibrated against real clock
							; timing (none found in this project) -- lower it
							; if an absent drive stalls boot too long, raise
							; it if a real, present card ever times out.
*******************************************
* Console I/O vector table
	ORG	$D3E5
INCHNE_T 	FDB	INCHNE
IHNDLR_T	FDB	IHNDLR
SWIVEC_T	FDB	SWIVEC
IRQVEC_T	FDB	IRQVEC
TMOFF_T		FDB	TMOFF
TMON_T		FDB	TMON
TMINT_T		FDB	TMINT
MONITR_T	FDB	MONITR
TINIT_T		FDB	TINIT
STAT_T		FDB	STAT
OUTCH_T		FDB	OUTCH
INCH_T		FDB	INCH
*******************************************
* DISK I/O vector table -- FLEX's own core calls into this with a plain
* JSR straight to the fixed address (e.g. "JSR $DE00"), NOT an indirect
* jump through a pointer -- see TSC's FLEX Advanced Programmer's Manual:
* "All routines are entered with a JSR instruction" to fixed, 3-byte-
* spaced addresses, each containing an actual JMP instruction. This used
* to be a table of FDB pointers (2 bytes apart) instead of real JMP
* instructions (3 bytes apart) -- which meant a real "JSR $DE00" from
* FLEX executed the raw address BYTES of READ as if they were an opcode
* (e.g. $F8 = LDB extended) instead of ever reaching READ at all. That
* silently broke every single disk driver entry point for FLEX itself,
* while our own test tools (which called through here with JSR [READ_T]
* etc., matching the old pointer format) worked fine and masked it.
	ORG	$DE00
READ_T 		JMP	READ
WRITE_T		JMP	WRITE
VERIFY_T	JMP	VERIFY
RESTORE_T	JMP	RESTORE
DRIVE_T		JMP	DRIVE
CHKRDY_T	JMP	CHKRDY
QUICK_T		JMP	QUICK
INIT_T		JMP	INIT
WARM_T		JMP	WARM
SEEK_T		JMP	SEEK
*******************************************

MONITOR		EQU		$E03C			; Monitor entry point
*******************************************
* Flex I/O routines 
*******************************************
	ORG	$F800
********************************
* PROGRAM VARIABLES
********************************
CFADDCURNT	FCB		$00, $00
CFDRVCURNT	FCB		$00
*******************************************
* Console routines 
*******************************************
* Input character w/o echo *
INCHNE	PSHS	U				; Preserve the U register
INWAIT	LDU     #PORTA			; Load 68681 base address
        LDA     Status,U		; Load STATUS register
        LSRA					; Test receiver register flag
        BCC		INWAIT			; Wait if nothing
		NOP						; Bus recovery margin -- same fix as OUTCH:
		NOP						; reading RxBuff immediately after Status
								; gave the DUART no recovery time between
								; back-to-back accesses
        LDA		RxBuff,U		; Load DATA byte
		PULS	U				; Restore 'U'
   		RTS                     ; Return with received character in 'A'

* interrupt handler *		
IHNDLR	RTS						; Empty stub
				
* SWI interrupt handler *		
SWIVEC	RTS						; Empty stub
				
* IRQ interrupt handler *		
IRQVEC	RTS						; Empty stub
				
* Timer OFF routine *
TMOFF	RTS						; Empty stub
		
* Timer ON routine *
TMON	RTS						; Empty stub
		
* Timer initialisation *
TMINT	RTS						; Empty stub
		
* Return to the Assist09 monitor *
MONITR	LDU     #PORTA			; Load 68681 base address					; 
        LDA		#$80			; Re-enable the ROM
        STA		OPSet,U
		LBRA	MONITOR			; and jump into the monitor

* Terminal initialisation *
TINIT 	PSHS	A, X
		LDX		#PORTA
		LDA		#$10			; Reset MR pointer
		STA		Command, X
        LDA		#$93			; Configure the selected port as
        STA		ModeReg, X		; 8 bits & no parity & RTR
		LDA		#$34			; Set MR2 for 1 stop-bit
        						; Set bits 5, 4 to enable flow control
        STA		ModeReg, X
        LDA		#%01110000
        STA		AuxCont, X
        LDA		#$CC			; Set Rx & Tx speed to 38.4k
        STA		ClkSel, X
        LDA		#$20			; Reset the Rx
        STA		Command, X
        LDA		#$30			; Reset the Tx
        STA		Command, X
		LDA		#$45			; Enable Rx & Tx
        STA		Command, x
		LDA 	#$01			; Set the RTR Output
		STA		OPSet, X
		PULS A, X
       	RTS
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

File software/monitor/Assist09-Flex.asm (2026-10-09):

*************************************

*************************************
* THIS IS THE BASE ASSIST09 ROM.
* IT MAY RUN WITH OR WITHOUT THE
* EXTENSION ROM WHICH
* WHEN PRESENT WILL BE AUTOMATICALLY
* INCORPORATED BY THE BLDVTR
* SUBROUTINE.
*************************************

*********************************************
* GLOBAL MODULE EQUATES
********************************************
ROMBEG  EQU     $E000           ; ROM START ASSEMBLY ADDRESS
RAMOFS  EQU     -$7000          ; ROM OFFSET TO RAM WORK PAGE
ROMSIZ  EQU     $2000           ; ROM SIZE
ROMS2IZ EQU     $2000            ; ROM SIZE
ROM2OF  EQU     ROMBEG-ROM2SIZ  ; START OF EXTENSION ROM
ACIA    EQU     $F230           ; DEFAULT ACIA ADDRESS
PTM     EQU     $0000           ; DEFAULT PTM ADDRESS
DFTCHP  EQU     0               ; DEFAULT CHARACTER PAD COUNT
DFTNLP  EQU     5               ; DEFAULT NEW LINE PAD COUNT
PROMPT  EQU     ':              ; PROMPT CHARACTER
NUMBKP  EQU     8               ; NUMBER OF BREAKPOINTS
*********************************************

*********************************************
* MISCELANEOUS EQUATES
*********************************************
EOT     EQU     $04             ; END OF TRANSMISSION
BELL    EQU     $07             ; BELL CHARACTER
LF      EQU     $0A             ; LINE FEED
CR      EQU     $0D             ; CARRIAGE RETURN
DLE     EQU     $10             ; DATA LINK ESCAPE
CAN     EQU     $18             ; CANCEL (CTL-X)

* PTM ACCESS DEFINITIONS
PTMSTA  EQU     PTM+1           ; READ STATUS REGISTER
PTMC13  EQU     PTM             ; CONTROL REGISTERS 1 AND 3
PTMC2   EQU     PTM+1           ; CONTROL REGISTER 2
PTMTM1  EQU     PTM+2           ; LATCH 1
PTMTM2  EQU     PTM+4           ; LATCH 2
PTMTM3  EQU     PTM+6           ; LATCH 3
SKIP2   EQU     $8C             ; "CMPX #" OPCODE - SKIPS TWO BYTES

*******************************************
* ASSIST09 MONITOR SWI FUNCTIONS
* THE FOLLOWING EQUATES DEFINE FUNCTIONS PROVIDED
* BY THE ASSIST09 MONITOR VIA THE SWI INSTRUCTION.
******************************************
INCHNP  EQU     0               ; INPUT CHAR IN A REG - NO PARITY
OUTCH   EQU     1               ; OUTPUT CHAR FROM A REG
PDATA1  EQU     2               ; OUTPUT STRING
PDATA   EQU     3               ; OUTPUT CR/LF THEN STRING
OUT2HS  EQU     4               ; OUTPUT TWO HEX AND SPACE
OUT4HS  EQU     5               ; OUTPUT FOUR HEX AND SPACE
PCRLF   EQU     6               ; OUTPUT CR/LF
SPACE   EQU     7               ; OUTPUT A SPACE
MONITR  EQU     8               ; ENTER ASSIST09 MONITOR
VCTRSW  EQU     9               ; VECTOR EXAMINE/SWITCH
BRKPT   EQU     10              ; USER PROGRAM BREAKPOINT
PAUSE   EQU     11              ; TASK PAUSE FUNCTION
NUMFUN  EQU     11              ; NUMBER OF AVAILABLE FUNCTIONS

* NEXT SUB-CODES FOR ACCESSING THE VECTOR TABLE.
* THEY ARE EQUIVALENT TO OFFSETS IN THE TABLE.
* RELATIVE POSITIONING MUST BE MAINTAINED

.AVTBL  EQU     0               ; ADDRESS OF VECTOR TABLE
.CMDL1  EQU     2               ; FIRST COMMAND LIST
.RSVD   EQU     4               ; RESERVED HARDWARE VECTOR
.SWI3   EQU     6               ; SWI3 ROUTINE
.SWI2   EQU     8               ; SWI2 ROUTINE
.FIRQ   EQU     10              ; FIRQ ROUTINE
.IRQ    EQU     12              ; IRQ ROUTINE
.SWI    EQU     14              ; SWI ROUTINE
.NMI    EQU     16              ; NMI ROUTINE
.RESET  EQU     18              ; RESET ROUTINE
.CION   EQU     20              ; CONSOLE ON
.CIDTA  EQU     22              ; CONSOLE INPUT DATA
.CIOFF  EQU     24              ; CONSOLE INPUT OFF
.COON   EQU     26              ; CONSOLE OUTPUT ON
.CODTA  EQU     28              ; CONSOLE OUTPUT DATA
.COOFF  EQU     30              ; CONSOLE OUTPUT OFF
.HSDTA  EQU     32              ; HIGH SPEED PRINTDATA
.BSON   EQU     34              ; PUNCH/LOAD ON
.BSDTA  EQU     36              ; PUNCH/LOAD DATA
.BSOFF  EQU     38              ; PUNCH/LOAD OFF
.PAUSE  EQU     40              ; TASK PAUSE ROUTINE
.EXPAN  EQU     42              ; EXPRESSION ANALYZER
.CMDL2  EQU     44              ; SECOND COMMAND LIST
.ACIA   EQU     46              ; ACIA ADDRESS
.PAD    EQU     48              ; CHARACTER PAD AND NEW LINE PAD
.ECHO   EQU     50              ; ECHO/LOAD AND NULL BKPT FLAG
.PTM    EQU     52              ; PTM ADDRESS
NUMVTR  EQU     52/2+1          ; NUMBER OF VECTORS
HIVTR   EQU     52              ; HIGHEST VECTOR OFFSET

*********************************************
* MC68681 REGISTER EQUATES
********************************************
PORTA		EQU		$F340
PORTB		EQU		$F348
* Read registers
ModeReg		EQU     0           	; Mode Register 
Status		EQU     1         		; Status Register 
RxBuff		EQU     3         		; Receiver Buffer 
PortCR		EQU     4         		; Input Port Change Register
IntReg		EQU     5         		; Interrupt Staus Register
CounterMSBA	EQU     6         		; Counter Mode: MSB
CounterLSBA	EQU     7         		; Counter Mode: LSB
StartCount1	EQU     14        		; Start-counter command
StartCount2	EQU     15        		; Start-counter command

* Write registers
ClkSel		EQU     1          		; Clock-Select Register 
Command		EQU     2          		; Command register 
TxBuff		EQU     3          		; Transmitter buffer 
AuxCont		EQU     4          		; Auxillary control register
IntMask		EQU     5          		; Interrupt mask register
CTUpper		EQU     6          		; Counter/timer upper register
CTLower		EQU     7          		; Counter/timer lower register
OPSet		EQU     14         		; Output port set bits
OPReset		EQU     15         		; Output port reset bits

*********************************************


******************************************
*           WORK AREA
* THIS WORK AREA IS ASSIGNED TO THE PAGE ADDRESSED BY
* -$1800,PCR FROM THE BASE ADDRESS OF THE ASSIST09
* ROM. THE DIRECT PAGE REGISTER DURING MOST ROUTINE
* OPERATIONS WILL POINT TO THIS WORK AREA. THE STACK
* INITIALLY STARTS UNDER THE RESERVED WORK AREAS AS
* DEFINED HEREIN.
******************************************
WORKPG  EQU     ROMBEG+RAMOFS   ; SETUP DIRECT PAGE ADDRESS
*       SETDP   =WORKPG         ; NOTIFY ASSEMBLER
        ORG     WORKPG+256      ; READY PAGE DEFINITIONS
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

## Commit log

2022-08-10 Version 6 schematic, BOM and component placement
2024-04-29 Add files via upload
    Reads an s09 file and builds a memory map from the data. The address references are them sorted into ascending order and a new s09 file written back to disk. Flex.cor contains patches that overwrite previously assigned memory, and this filters these from the file, as srecord cannot handle multiple memory values when programming a PROM.
2024-07-22 Add files via upload
    The image is a composite of Assist09, the console drivers for Flex and an image of Flex 9.1.
    SortedFlex.s09 is a file that can be downloaded individually that is FLEX.COR - it is a full flex image, without the drivers included.
    Flex_BIOS.s09 contains the vector table that connects FLEX.COR with the console drivers, but does not contain the disk drivers.
    CF_Test_04.s09 is a utility for configuring CF Cards and reading/writing from/to them. This is used to create a Flex disk image on a CF Card, as part of bringing Flex to life.
    merged.hex is the image that can be programmed to the EEPROM.
2026-10-09 Reorganise repo and add current board software
    - hardware/: schematics and board files
    - tools/octave/: Octave FLEX and S-record scripts
    - software/: current monitor (with RTC and FLEX date handling), FLEX BIOS,
    disk-image loader, CF formatter and tests, RTC programs, ROM image v6,
    and XBASIC patching notes; replaces PROM_Image/ (older ROM pieces kept in
    software/rom-images/archive/)
    - Add README, MIT licence and third-party notice
    Claude-Session: https://claude.ai/code/session_01HDaeaZDkXxYUgGseNxwQDA
    [6809 EXPANDED V2 SBC.brd, 6809 EXPANDED V2 SBC.sch, Assist09_Added_Commands.xlsx]
2026-10-16 Add TIME, a FLEX command that prints the RTC time
    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
2026-10-16 Add .gitignore (macOS and abandoned KiCad experiment)
    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
2026-10-19 Add des: DESFILE file encryption with the MC6859
    DESFILE encrypts and decrypts FLEX text files with the MC6859 DES chip,
    as a TSC XBASIC program (DESFILE.BAS) and as a native FLEX command
    (DESFILE.asm / DESFILE.CMD). Both use the same hex file format and have
    been checked on the board to work interchangeably.
    Claude-Session: https://claude.ai/code/session_019J6Q1NR6m68X5x6XDwPkcx
2026-10-19 Add PiMac: the same π method on a Mac, for comparison
    PiMac.swift is a single-file SwiftUI app running exactly the algorithm
    used by PI.CMD, with no tuning for the Mac (one thread, one digit per
    byte, Machin's formula). It shows the digits in a window and can save
    them. The pi README gains a comparison table: about 29,000 times the
    speed of the 2 MHz 6809 at both 1,000 and 100,000 digits.
    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
2026-10-20 PiMac: allow a million digits, record the 1M run
    Raise PiMac's limit to 1,000,000 digits. A million-digit run on the
    Mac took 3.5 hours of calculation, which is added to the comparison in
    the pi README along with the likely reasons it scales worse than the
    smaller runs.
    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
2026-10-21 Boot to Microsoft Extended BASIC when it is in the ROM
    The monitor's reset now copies the ROM to RAM and starts BASIC at $9C00
    if the byte there is $7E (JMP), otherwise Assist09 as before. BASIC's
    new MONITOR and FLEX commands come back through MONENT via the 6809's
    unused reserved vector at $FFF0. $E03C is still the monitor entry used
    by FLEX's MON and the clock program.
    BASIC itself is Microsoft's code and is not included; docs/basic-port.md
    describes the changes to Grant Searle's port, including the bracket
    fixes a09 needs for expressions AS9 evaluates left to right.
    - monitor: BOOT, MONENT, COPYOFF; reset vector -> BOOT, $FFF0 -> MONENT
    - FLEX-core.hex: drop $FF padding at $E884-$E89F,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
2026-10-21 PI.CMD: divide by 25 as a multiply by 4 and a two-digit shift
    Because the digits are decimal, P/25 = 4P/100: multiply each digit by
    4 with carry and write it two places on. The new DIV25 routine gives
    exactly the same digits as the divide at 67 cycles per digit instead of
    212. 1,000 digits now take 1:58 on the 2 MHz board (was 2:20) and 3:56
    at 1 MHz. The README describes the idea and how to try it in the BASIC
    versions, which are left unchanged.
    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
2026-10-21 basic-port: show MEM as an unsigned number
    MEM converted the free byte count as a signed 16-bit value, so with
    about 39 KB free it printed -26410. Change 9 gives it the unsigned
    conversion Microsoft already uses at LBDCC for line numbers. BASIC now
    ends at $BFF3; README and the added-commands spreadsheet updated to
    match.
2026-10-28 BASIC: FLEX disk commands, and the board's additions in their own file
    software/basic/BasicSBC.asm (MIT) holds everything added to Microsoft
    Extended BASIC that isn't a small change to Microsoft's own code:
    MONITOR, FLEX, an unsigned MEM, and five commands that work with FLEX
    disks through the BIOS jump table at $DE00:
    CAT [drive], CATW [drive] directory, in full or names only
    LOAD "spec" / LOAD load a file / reload the current one
    SAVE "spec" / SAVE new file (never overwrites) / update
    DELETE "spec" caught at DEL, which tokenises first
    Programs are FLEX text files, as LIST shows them. Writes are ordered so
    an interrupted SAVE or DELETE can only lo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
